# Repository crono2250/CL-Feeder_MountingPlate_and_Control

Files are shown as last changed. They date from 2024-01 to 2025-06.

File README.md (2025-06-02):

# CL-Feeder_MountingPlate_and_Control
Mechanical component data and firmware for control to utilize Yamaha's CL feeders in OpenPnP

All plate parts are assumed to be CNC machined and anodized A7075.

A rubber ring is needed to provide compressed air to the feeder.
This can be purchased at Robotdigg.
https://www.robotdigg.com/product/1011
<br>
- machine photo<br>
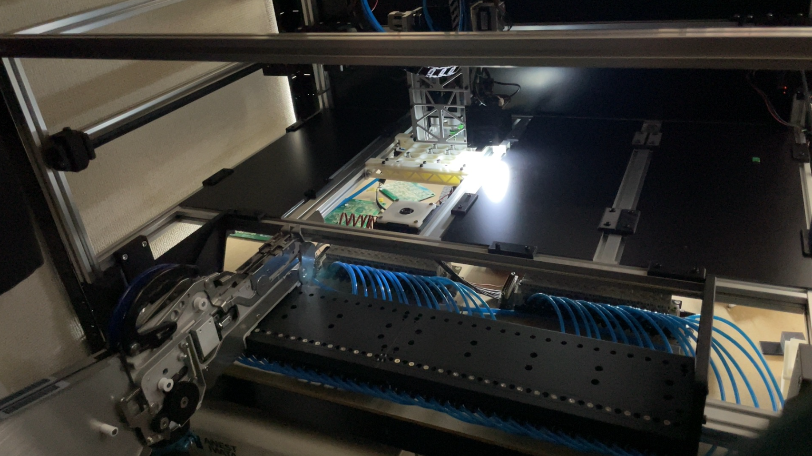
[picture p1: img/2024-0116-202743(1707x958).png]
  
<br>

- movie(Link to Youtube<br>
mounter_movie (https://youtu.be/XUIm4a0VSz8)

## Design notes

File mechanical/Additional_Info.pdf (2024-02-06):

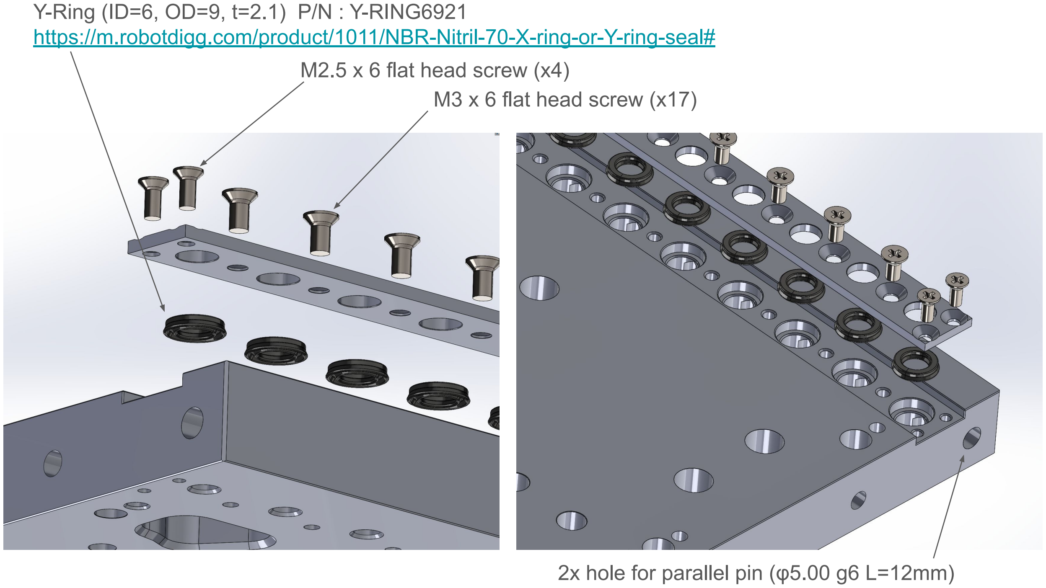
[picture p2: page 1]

M3 x 6 flat head screw (x17)

M2.5 x 6 flat head screw (x4)

Y-Ring (ID=6, OD=9, t=2.1) P/N : Y-RING6921 https://m.robotdigg.com/product/1011/NBR-Nitril-70-X-ring-or-Y-ring-seal#

2x hole for parallel pin (φ5.00 g6 L=12mm)

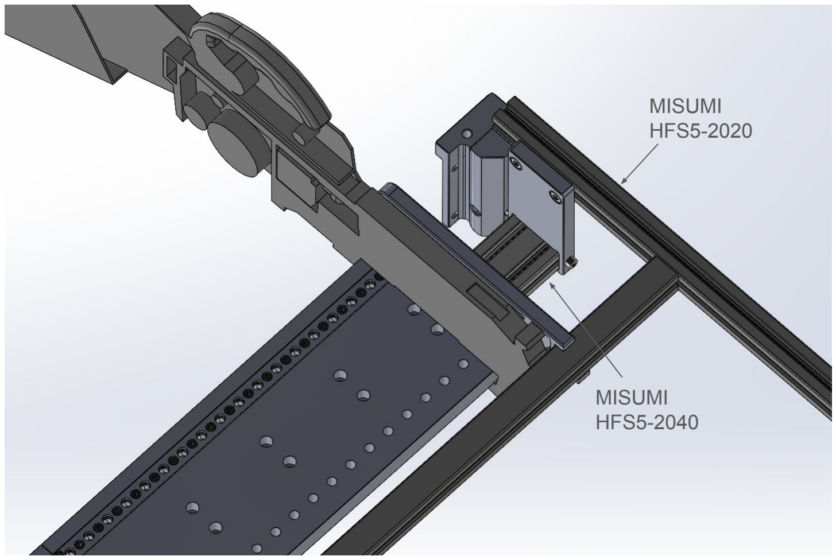
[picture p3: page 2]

MISUMI
HFS5-2020

MISUMI
HFS5-2040

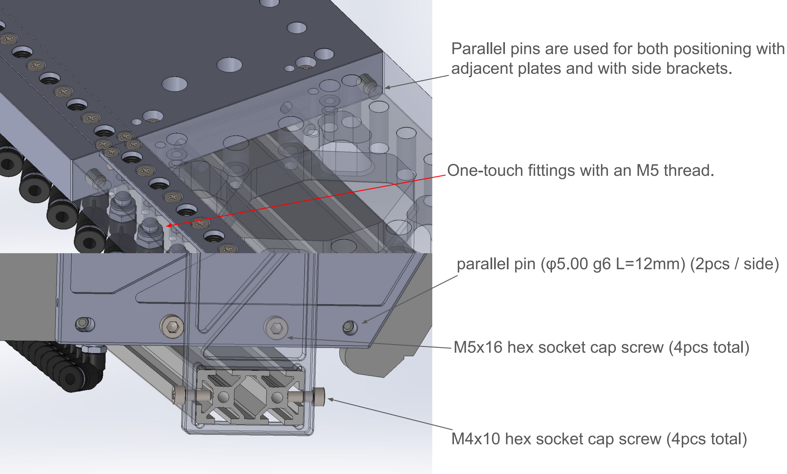
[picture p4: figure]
M5x16 hex socket cap screw (4pcs total); adjacent plates and with side brackets.; One-touch fittings with an M5 thread.; M4x10 hex socket cap screw (4pcs total)

parallel pin (φ5.00 g6 L=12mm) (2pcs / side)

Parallel pins are used for both positioning with

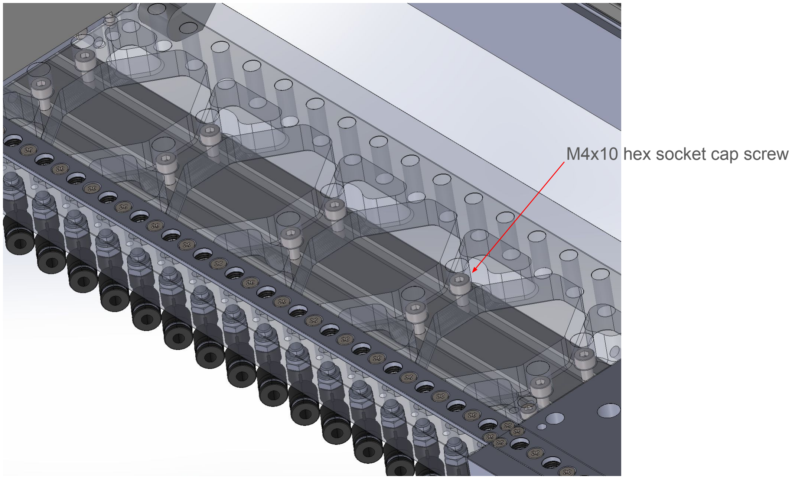
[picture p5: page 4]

M4x10 hex socket cap screw

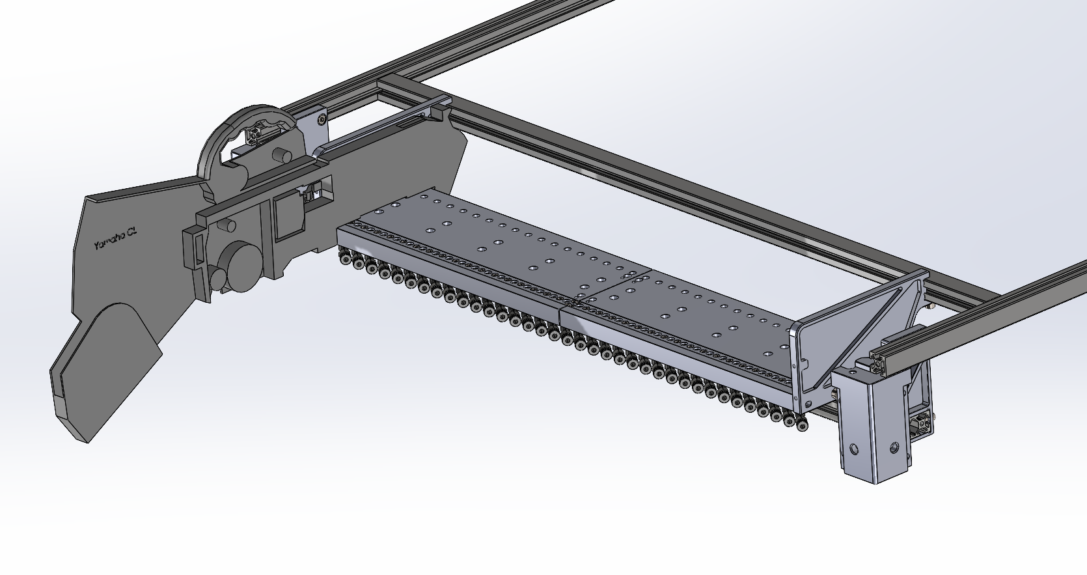
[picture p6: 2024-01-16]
mechanical/img/Assy_Image.png

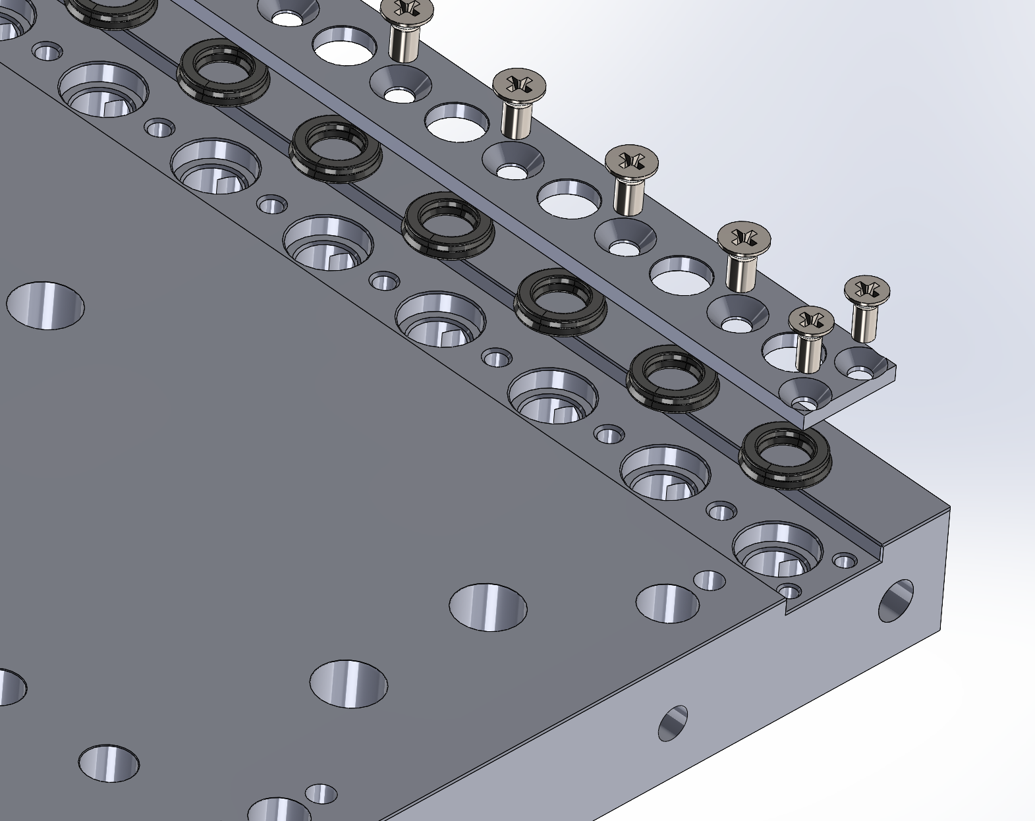
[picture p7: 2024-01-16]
mechanical/img/Screw-Yring.png

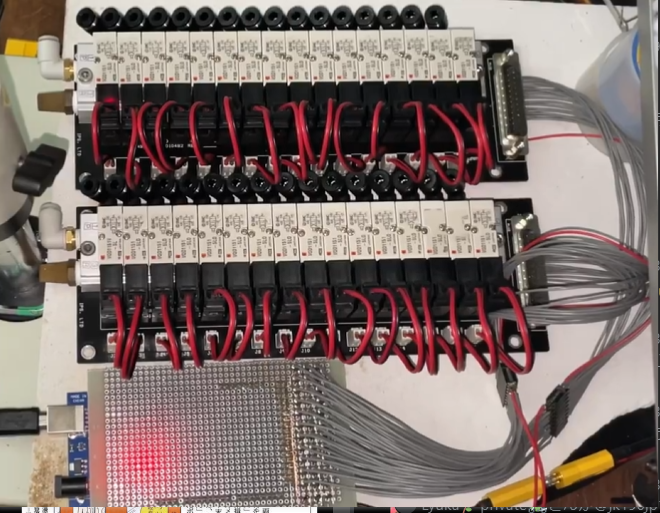
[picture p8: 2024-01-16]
firmware/Hardware.png

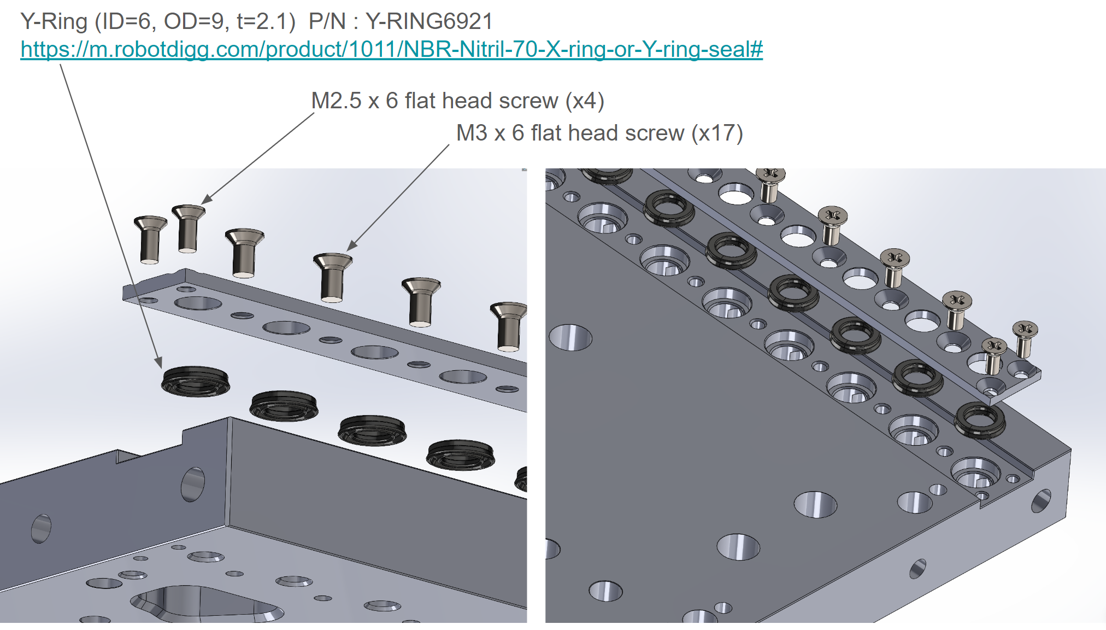
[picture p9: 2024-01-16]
img/2024-0116-184138(2024x1152).png

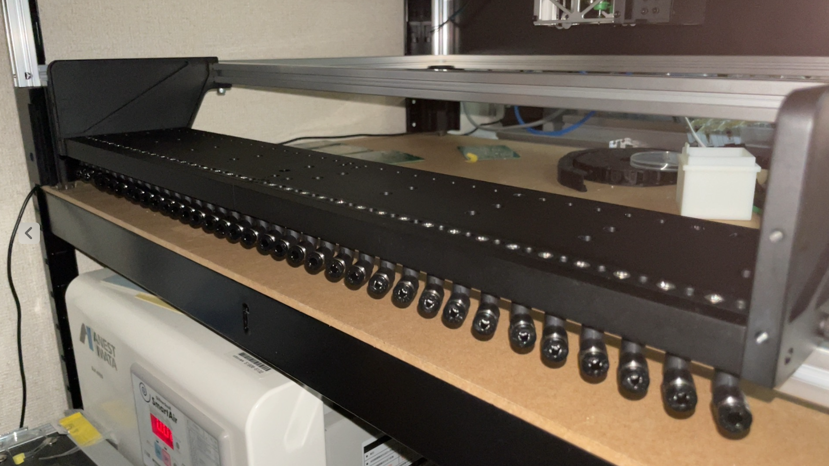
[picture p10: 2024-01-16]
img/2024-0116-202703(1703x957).png

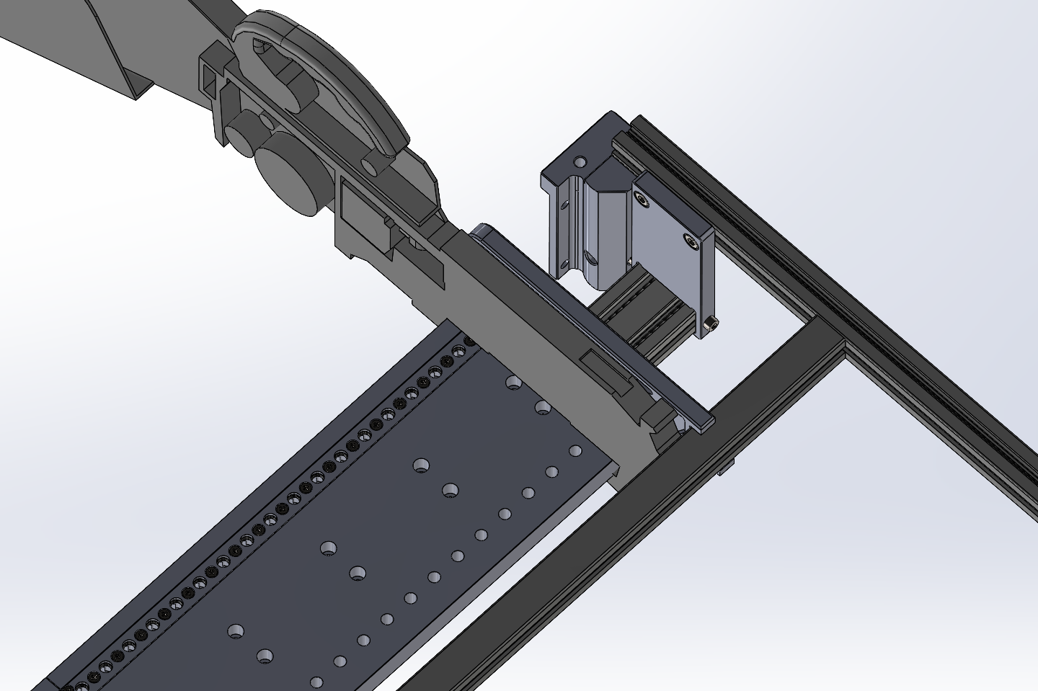
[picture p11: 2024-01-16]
img/2024-0116-184406(1440x959).png

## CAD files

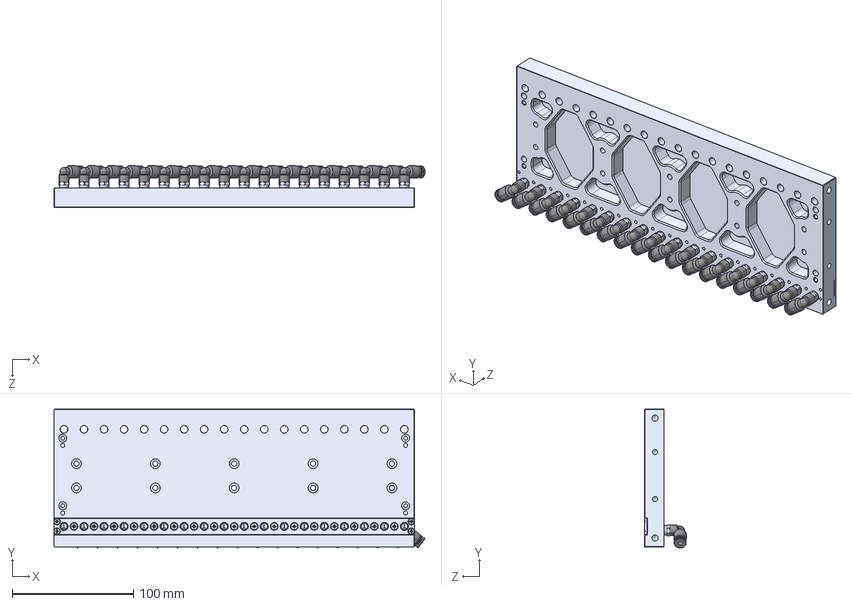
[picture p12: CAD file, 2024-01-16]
mechanical/Assy/Yamaha_CL_BasePlate_18Feeder_SubAssy.STEP
305.7 x 114.5 x 34.2 mm
Yamaha_CL_BasePlate_18Feeder
Yamaha_CL_BasePlate_SealPlate_18Feeder
cross recessed countersunk head screw_jis_JIS 1111 Cross recessed countersunk head screw - M2.5 x 6 - Z --6N x 4
cross recessed countersunk head screw_jis_JIS 1111 Cross recessed countersunk head screw - M3 x 6 - Z --6N x 17
masuoka_MY-6 x 18
PL4-M5_ x 18

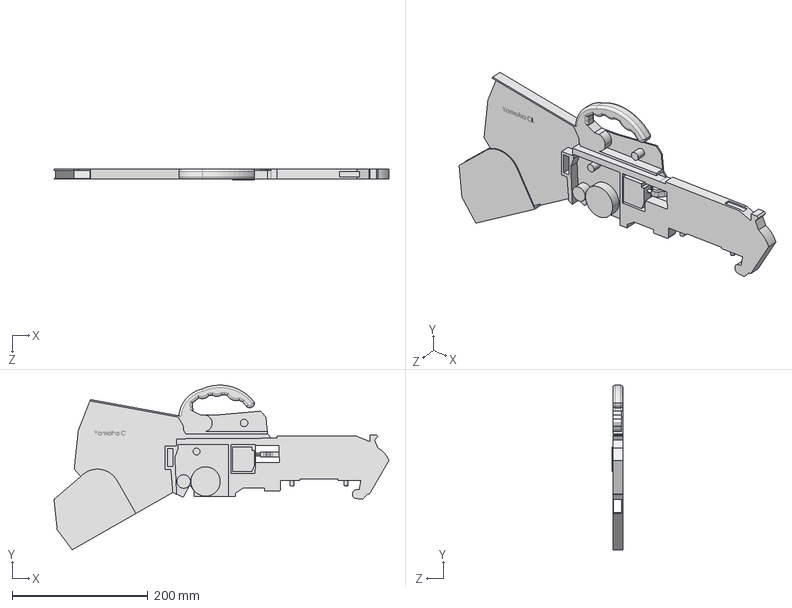
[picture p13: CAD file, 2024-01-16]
mechanical/parts/Yamaha_CL_8.STEP
493.7 x 242.7 x 16.0 mm

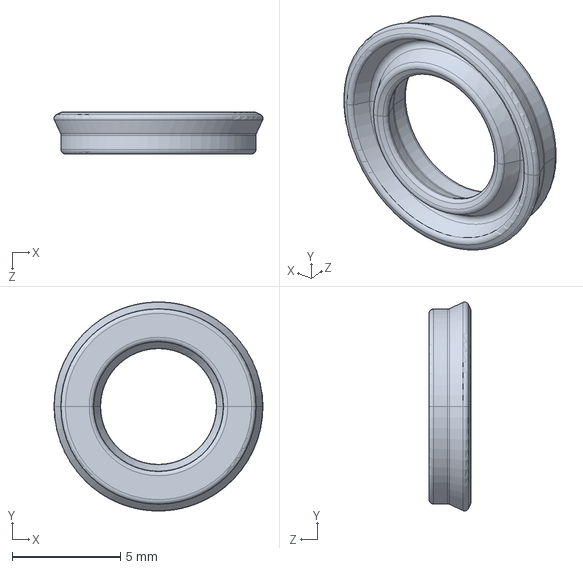
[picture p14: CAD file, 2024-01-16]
mechanical/parts/masuoka_MY-6.STEP
9.65 x 9.65 x 1.94 mm

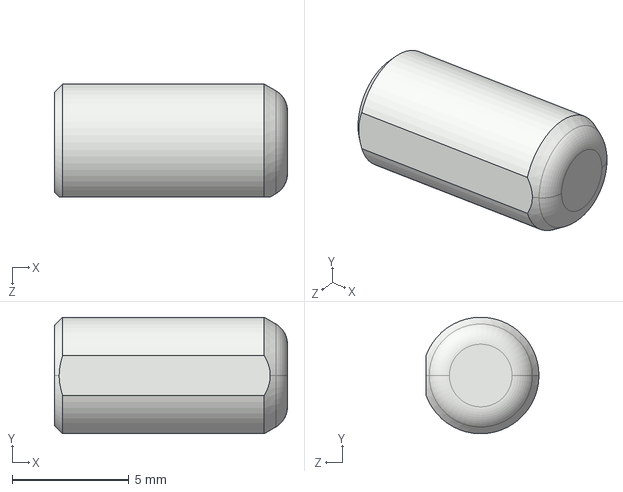
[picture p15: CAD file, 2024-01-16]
mechanical/parts/LPT5-10.STEP
10.0 x 5.00 x 4.85 mm

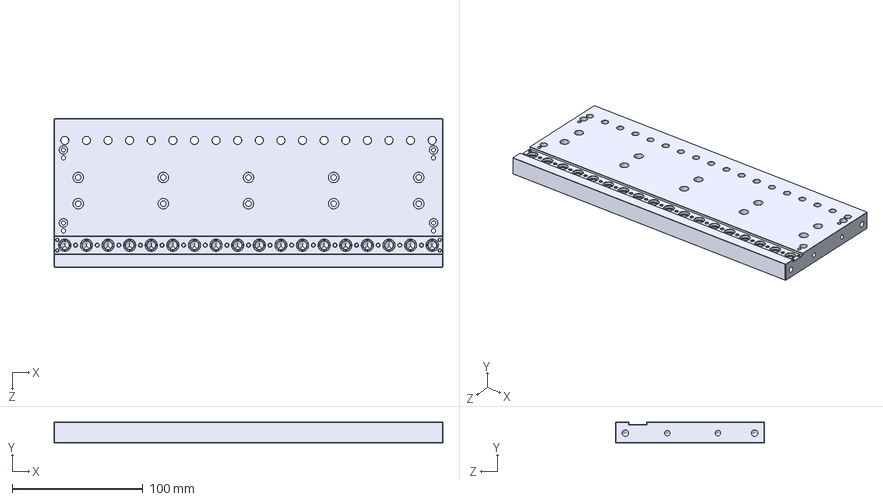
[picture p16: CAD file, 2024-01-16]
mechanical/parts/Yamaha_CL_BasePlate_18Feeder.STEP
297.0 x 16.0 x 113.7 mm

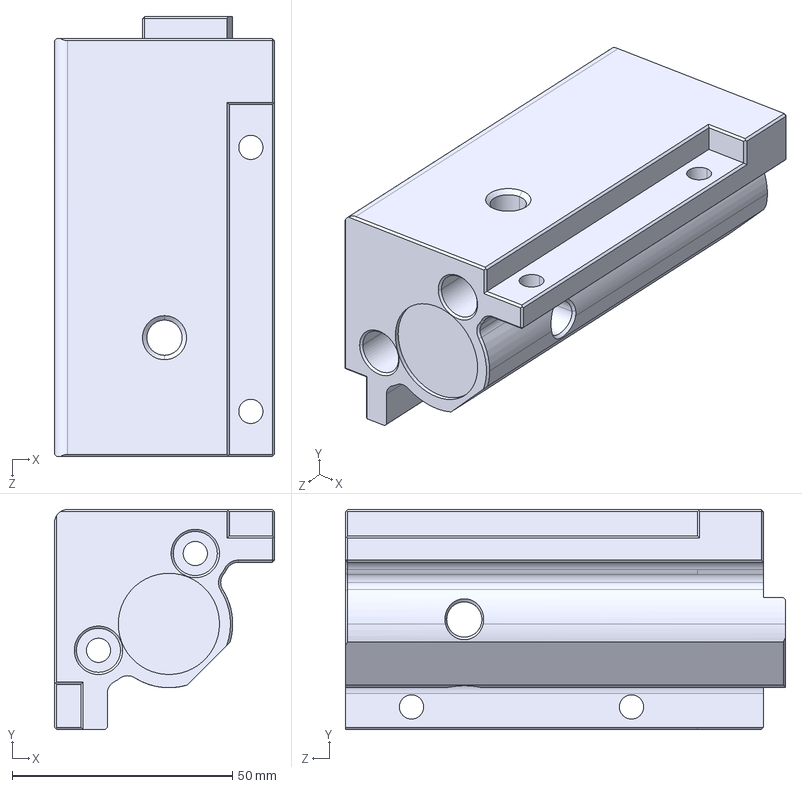
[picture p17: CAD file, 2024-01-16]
mechanical/parts/Skirt_A.STEP
50.0 x 50.0 x 100.0 mm

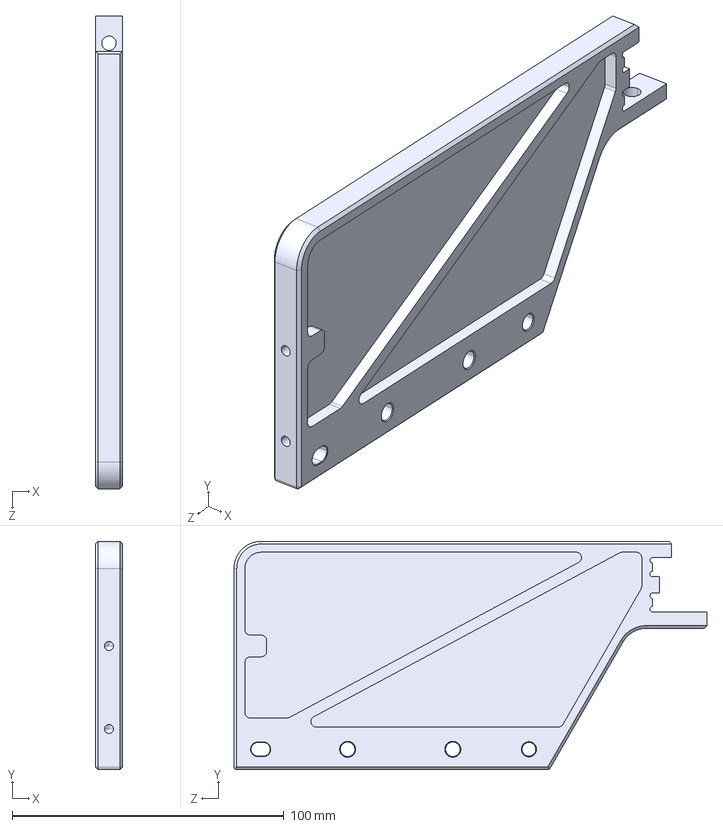
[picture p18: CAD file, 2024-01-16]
mechanical/parts/Yamaha_CL_Feeder_SideBracket.STEP
10.0 x 84.0 x 174.0 mm

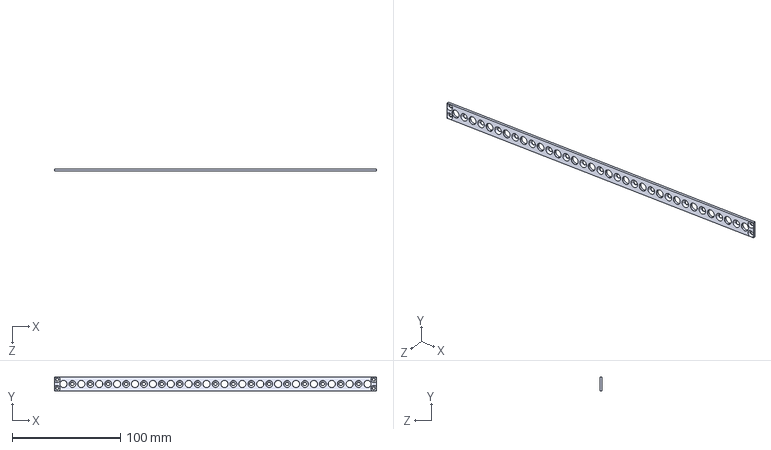
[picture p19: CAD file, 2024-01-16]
mechanical/parts/Yamaha_CL_BasePlate_SealPlate_18Feeder.STEP
297.0 x 13.2 x 2.00 mm

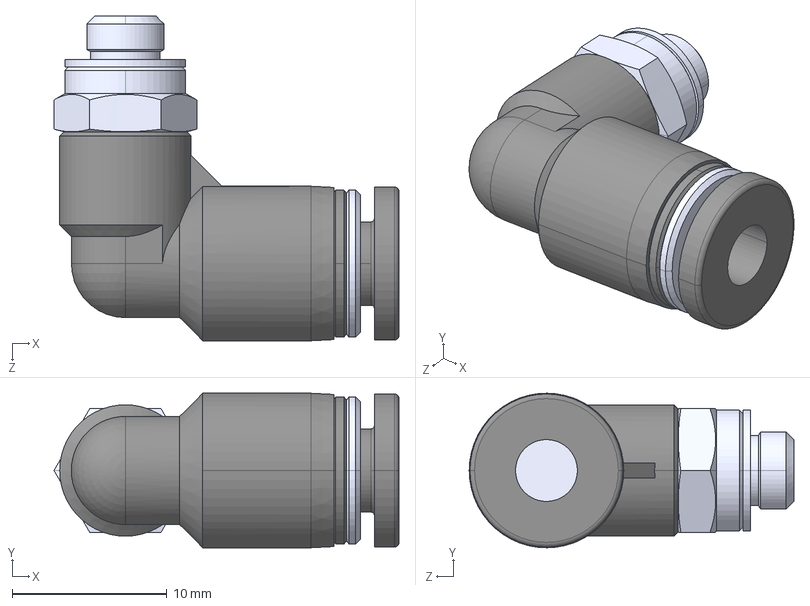
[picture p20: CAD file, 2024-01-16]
mechanical/parts/PL4-M5_.STEP
22.3 x 10.00 x 21.0 mm

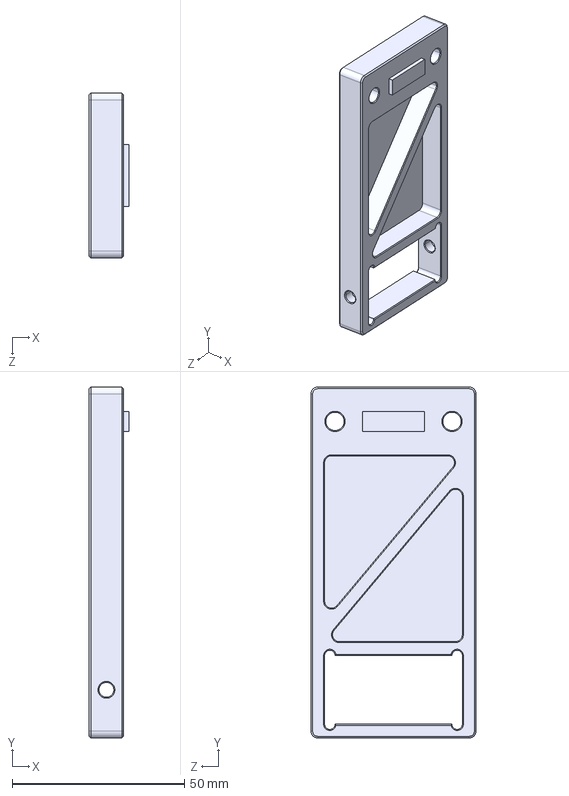
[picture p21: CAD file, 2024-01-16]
mechanical/parts/Feeder_BasePlate_VoronMount.STEP
11.5 x 102.0 x 48.0 mm

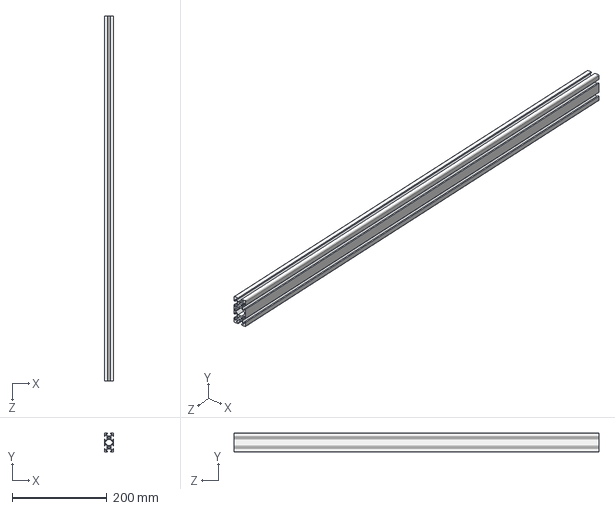
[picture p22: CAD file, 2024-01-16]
mechanical/parts/NFS5-2040-770_misumi.STEP
20.0 x 40.0 x 770.0 mm

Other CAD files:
mechanical/parts/Yamaha_CL_BasePlate_18Feeder.DXF
mechanical/parts/Yamaha_CL_Feeder_SideBracket.DXF

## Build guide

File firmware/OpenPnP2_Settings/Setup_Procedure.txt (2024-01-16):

0. [ Arduino ] Actuator firmware build and write
    Build OpenPnP_CL-Feeder_mega2560.ino and write it to Arduino mega2560.

1. [ OpenPnP2 ] Add a G-code driver
    1.1 Add GCodeAsyncDriver and set the name "CL-Feeder_Driver" in the Name area of the Configuration tab.
    1.2 Set "Line-Endings" to "LF" in the Communication method area of the Configuration tab.
    1.3 In the SerialPort area of the Configuration tab, set "Port" to the COM port that was added when the driver was connected.
    1.3 Set "Baud" to "115200" in the SerialPort area of the Configuration tab.

2. [ OpenPnP2 ] Add Actuator
    2.1 Add two "ReferenceActuator" and name them "CL-Feeder_PrePick", "CL-Feeder_PostPick
    2.2 Specify "CL-Feeder_Driver" as the "Driver" of the added actuators.

3. [ OpenPnP2 ] Add Actuator Settings
    3.1 Select "CL-Feeder_Driver" added to "Drivers".
    3.2 Select the "Gcode" tab, and select "CL-Feeder_PrePick" from the "Head Mountable" drop-down list.
    3.3 Select "COMMAND_DOUBLE_COMMAND" from the "Setting" drop-down list.
    3.4 Add "M600 N{IntegerValue} S1"

    3.5 Select the "Gcode" tab, and select "CL-Feeder_PostPick" from the "Head Mountable" drop-down list.
    3.6 Select "COMMAND_DOUBLE_COMMAND" from the "Setting" drop-down list.
    3.7 Add "M600 N{IntegerValue} S0"

4. [ OpenPnP2 ] Adding and configuring feeders
    4.1 Set "CL-Feeder_PrePick" to "Feed" of "Actuator" in the "Actuators" area.
    4.2 Set "CL-Feeder_PostPick" to "Post Pick" of "Actuator" in the "Actuators" area.
    4.3 In the "Feeders" tab, add "ReferenceAutoFeeder".
        Write the slot number in the "Actuator Value" in the "Actuators" area. The two numbers must have the same value.
    4.4 Repeat section 4.3 for the number of slots.

5. [ OpenPnP2 ] Check if it works
    5.1 Click on "CL-Feeder_PrePick" in the "Actuators" tab under "Machine Controls
    5.2 Enter a slot number (e.g. 0) in the "Set value" field and press the "Set" button.
    5.3 Confirm that the Arduino port corresponding to slot 0 is set to "High" level. (The attached firmware changes the level of GPIO33.)

    5.4 Click "CL-Feeder_PostPick" in the "Actuators" tab under "Machine Controls".
    5.5 Enter a slot number (e.g. 0) in the "Set value" field and press the "Set" button.
    5.6 Confirm that the Arduino port corresponding to slot 0 is set to "Low" level. (The attached firmware changes the level of GPIO33.)

6. Enjoy!

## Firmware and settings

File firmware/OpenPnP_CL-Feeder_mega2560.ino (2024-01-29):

//---------------------------------
// Pneumatic valve controller for OpenPnP
//
// Modified by cronos_sv
// Date : 2024/Jan/29_1805
//
// target : Arduino Mega2560
//---------------------------------
#define MaxPinCount 36
//#define CommandDebug

 // Define power control pins
const uint8_t Power_Control_Pin = A15;  // Not used at this time.

const uint8_t Motor_Control_Pin[MaxPinCount] = {
  33, 32, 31, 30, 29, 28, 27, 26,
  25, 24, 23, 22, 21, 20, 19, 18,
  49, 48, 47, 46, 45, 44, 43, 42,
  41, 40, 39, 38, 37, 36, 35, 34,
  50, 51, 52, 53
};


// Variables
uint8_t pinValue = 0;     // Store Pin value
uint8_t pulseValue = 0;   // Store impulse value
uint16_t cmdValue = 0;    // Store command value
uint8_t rxCount = 0;      // Used for serial port receiving count
char rxBuffer[200] = {0}; // Store data received by serial port

void setup()
{
  Serial.begin(115200);                   // Initialize serial port, baud rate 9600
  pinMode(Power_Control_Pin, OUTPUT);   // Set the power control pin to output mode
  digitalWrite(Power_Control_Pin, LOW); // Set the power control pin output low level
  for (uint8_t i = 0; i < MaxPinCount; i++)      // 
  {
    pinMode(Motor_Control_Pin[i], OUTPUT);         // Set the motor control pin to output mode
    digitalWrite(Motor_Control_Pin[i], LOW);       // Set the motor control pin output low level
  }

  delay(1500);  // Prevent feeder malfunction at startup.
}

void loop()
{
  while (Serial.available()) // Cycle until no data is readable on the serial port
  {
    rxBuffer[rxCount] = Serial.read(); // Read one bit data
    if (rxBuffer[rxCount] == '\n')     // If the terminator is received
    {
      rxBuffer[rxCount] = 0;    // Set packet Terminator
      Serial.println(rxBuffer); // Print received data
      Unpack_Data();            // Parse data
      rxCount = 0;              // Restart receiving data
    }
    else                //
      rxCount++;      // 
    if (rxCount >= 200) // If the received data exceeds the size of the serial port buffer array
      rxCount = 0;    // Restart receiving
  }
}

void Unpack_Data(void)
{
  char *Tail = NULL, *Head = NULL;            // Pointer to store parsing data
  if ((Head = strchr(rxBuffer, 'M')) != NULL) // If M is found
  {
    if ((Tail = strchr(Head, ' ')) != NULL) //If a space character is found
    {
      *Tail = 0;                 //Truncate string
      cmdValue = atoi(Head + 1); // 

      if (cmdValue == 610)       // 610 mean Winder-motor Main Power Control
      {
        if (strstr(Tail + 1, "S1") != NULL) // If S1 is searched
        {
          digitalWrite(Power_Control_Pin, HIGH); // Power on
          Serial.print(F("ok "));
#ifdef CommandDebug
          Serial.print(1);                       //
#endif
        }
        else if (strstr(Tail + 1, "S0") != NULL) // If S0 is searched
        {
          digitalWrite(Power_Control_Pin, LOW); // Turn off the power
#ifdef CommandDebug
          Serial.print(0);                      // 
#endif
            for (uint8_t i = 0; i < MaxPinCount; i++)      // 
            {
              digitalWrite(Motor_Control_Pin[i], LOW);       // Set the motor control pin output low level
            }
            Serial.print(F("ok "));
        } else {
          Serial.print(F("error "));
        }
      }

      else if (cmdValue == 600) // 600 mean Servo-pin control of any port
      {
        Head = strchr(Tail + 1, 'N');             // Find N
        Tail = strchr(Head, ' ');                 // Find spaces
        *Tail = 0;                                // Truncate string
        pinValue = atoi(Head + 1);                // Get pin number

        pulseValue = 0;
        Head = strchr(Tail + 1, 'S');             // Find S
        pulseValue = atoi(Head + 1);              // Get propulsion value

        if(pinValue < MaxPinCount)
        {
#ifdef CommandDebug
          Serial.print(cmdValue);    // 
          Serial.print(",");         // 
          Serial.print(pinValue);                   // 
          Serial.print(",");                        // 
          Serial.print(pulseValue);                 // 
#endif
          digitalWrite(Motor_Control_Pin[pinValue], pulseValue);
          delay(80);      // The time required for the feeder mechanism to move.
          Serial.print(F("ok "));
        } else
        {
          Serial.print(F("error "));
#ifdef CommandDebug
          Serial.print("###ERR : M");
          Serial.print(cmdValue);
          Serial.print(" Invalid Port Number");
          Serial.println(); //
          Serial.print("         Valid Port Number : 0 to ");
          Serial.print(MaxPinCount-1);
#endif
        }
      }
      Serial.println(); //
    } else
    {
      cmdValue = atoi(Head + 1); // 
      if (cmdValue == 114)            // 114 is respond with the fixed string "X:0.0"
      {
        Serial.print(F("X:0.0 "));
        Serial.println();
        Serial.print(F("ok "));
      }
       else if (cmdValue == 115)            // 115 mean Inform System Information to OpenPnP
      {
        Serial.print(F("FIRMWARE_NAME: OpenPnP_CL-Feeder_mega2560 NUMBER_OF_FEEDERS: 0_to_"));
        Serial.print(MaxPinCount-1);
        Serial.print(F(" ELECTRONICS: CL-Feeder Driver for mega2560 FIRMWARE_VERSION: 24.1.29_1805 "));
        Serial.println();
        Serial.print(F("ok "));
      }
      Serial.println(); //
    }
  }
}

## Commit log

2024-01-16 initial commit
    Mechanical parts and firmware for control
    [Feeder_BasePlate_VoronMount.STEP, LPT5-10.STEP, NFS5-2040-770_misumi.STEP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]
2024-01-29 Update OpenPnP_CL-Feeder_mega2560.ino
    Correction on the handling of M114 as advised in forum
    - M114 commands now respond with the fixed string "X:0.0"
    Corrected M115 response string
    - Moved feeder slot count information from M114
    [OpenPnP_CL-Feeder_mega2560.ino]
2024-01-29 Update OpenPnP_CL-Feeder_mega2560.ino
    Corrected comment on M114.
    [OpenPnP_CL-Feeder_mega2560.ino]
2024-02-06 Document Update
    Added information on screws and parallel pins
